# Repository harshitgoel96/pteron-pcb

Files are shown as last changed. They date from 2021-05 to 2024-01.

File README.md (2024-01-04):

# Pteron36 Split Keyboard
## Intro 
Pteron36 PCB Render   

This project is the split evolution of the [pteron-pcb](https://github.com/Kraken-Jokes/pteron-pcb) project, which itself is the evolution of the [Pteron-Keyboard](https://github.com/FSund/pteron-keyboard) project, an incredible ergonomic keyboard that was handwired only.

The keyboard is being desinged to be used with [Miryoku-layout](https://github.com/manna-harbour/miryoku), this layout out aims to have efficient use of split keyboard.

NOTE: The keyboard design has reached its goal, I will not be doing any more development on this board. The support will still be provided. Any issues found by community will be addressed.
NOTE: Update Jan 4th, 2023, a few people have reached out to me with intentions to use the 38key version of the keyboard. The firmware changes have not been merged with QMK mainline yet. For the timebeing, please use this [forked branch to use 38key firmware](https://github.com/harshitgoel96/qmk_firmware/tree/pteron36_38/keyboards/pteron36). I will be working to update the firmware and merge it into the mainline.

#### BOM
| Component | part number | QTY | Comment |
| --- | --- | --- | --- |
| PCB | Gerber in release section | 2 | |
| Diode | 1n4148, SOD123 for smd, or Through hole | 38/36/34  | |
| ProMicro/Bluemicro  | | 2 | Firmwaree not merged with QMK/ZMK, reach out to me on how to build the firmware  |
| TRRS Jack | PJ-320A | 2 | |
| Switches | Cherry, Alps, Choc | 38/36/34  | check PCB compatibility section for more infromation |
| Keycaps | your choice | 38/36/34  | |
| TRRS Cable | TRRS cables have 3 black rings, make sure to check the number | 1 | |

#### BOM for optional components
| Component | part number | QTY | Comment |
| --- | --- | --- | --- |
| Mini tactile switch | PTS526 SMG15 SMTR2 LFS | 2 | You can use tweasers to Reset promicro |
| Rotary Encoder | EC11 | 2 | QMK, VIAL ✔️ ZMK 🚧 |
| OLED | 128x32 SSD1306 I2C | 2 | QMK, VIAL ✔️ ZMK 🚧 |

## Built keyboard
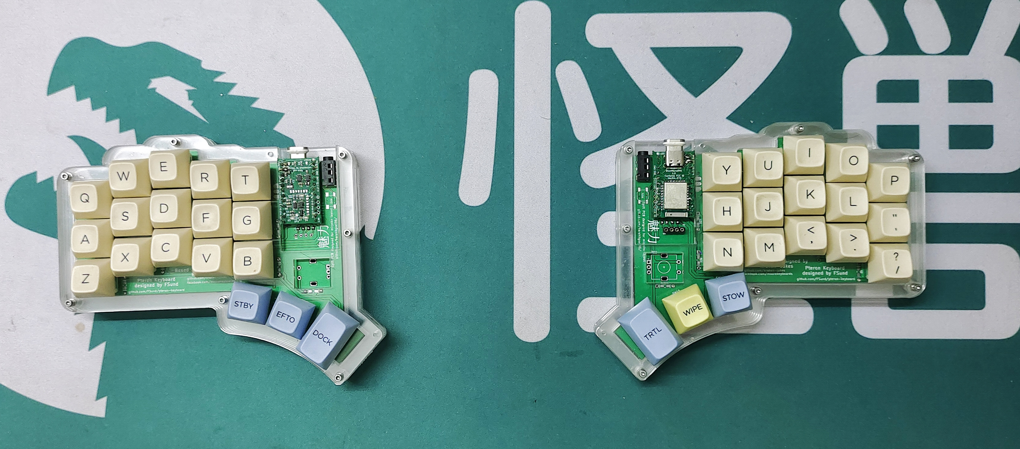
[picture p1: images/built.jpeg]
Pteron36 keyboard


## Build guide
Build guide is added in BUILD.md file.

## Firmware file
Pteron36 has been merged into QMK master with support for miryoku and via. VIA config in available in release section.
Pteron36 has been merged into VIAL QMK fork. 

## Important
The PCB and the case have been tested with MX Switches. 

### PCB compatibility matrix
| PCB version | MX Support | Alps Support | Choc support | Remark |
|---|---|---|---|---|
| V1.1.0 | :heavy_check_mark: |:heavy_check_mark: | :x: | |
| V1.2.0 | :heavy_check_mark: |:heavy_check_mark: | :heavy_check_mark: | |
| V1.3.0 | :heavy_check_mark: |:heavy_check_mark: | :heavy_check_mark: | Cleaner trace routing, added mounting holes |
| V1.4.0 | :heavy_check_mark: |:heavy_check_mark: | :heavy_check_mark: | Replaced sharp angle with curves, more cleaner pcb look |
To use choc switches, make sure to use V1.2.0 files from release section.

### Case compatibility

| Case Type | MX Support | Alps Support | Choc support |
|---|---|---|---|
| Acrylic | :heavy_check_mark: |:x: | :exclamation: Untested, plate need to be lasered on 2mm sheet |
| 3D Printed | 	:construction: Design complete, testing first prototypes |:x: | 	:construction: Design complete, testing first prototypes |

Tenting support added, need M4 screws for tenting holes.
### Acrylic Case assembly
Keyboard supports both ProMicro, and nrf52840 based Bluetooth promicro (bluemicro,nice!nano, etc). The case height will be different to accomodate batteries.
The case designed to be done 3mm acrylic.
Screw M2 6mm 36 nos
Standoff HEX M2 6mm or 9mm 18 nos

For tenting you need.
4x M4 25mm-30mm screws.
4x M4 15mm screws.
8x M4 dome nuts for screw bottom.
8x M4 nut for holding case at required height.
#### Case config for ProMicro
All 4 files need to be cut twice so total 8 pieces. 4 per half.
Screw and standoff needs to be M2. Standoff lenght will be 6mm. Screw length will be 5-6mm. 

#### Case config for Bluemicro, Nine!nano
The case will be taller by 3mm to accomodate battery. This is assuming battery battery thickness is between 3mm - 4mm. For thickerbattery add close layer and standoff length as required.
Close.dfx will be cut 4 times, rest all 3 files need to be cut twice so total 10 pieces. 5 per half.
Screw and standoff needs to be M2. Standoff lenght will be 9mm. Screw length will be 5-6mm.

## ToDo List (In order or priority)
* Add build guide. :construction:
* OLED Support in ZMK  :construction:. OLED working in QMK now  :heavy_check_mark: 
* Encoder Support in ZMK  :construction:. Encoder working in QMK now  :heavy_check_mark: 
* Get firmware merged and ZMK.

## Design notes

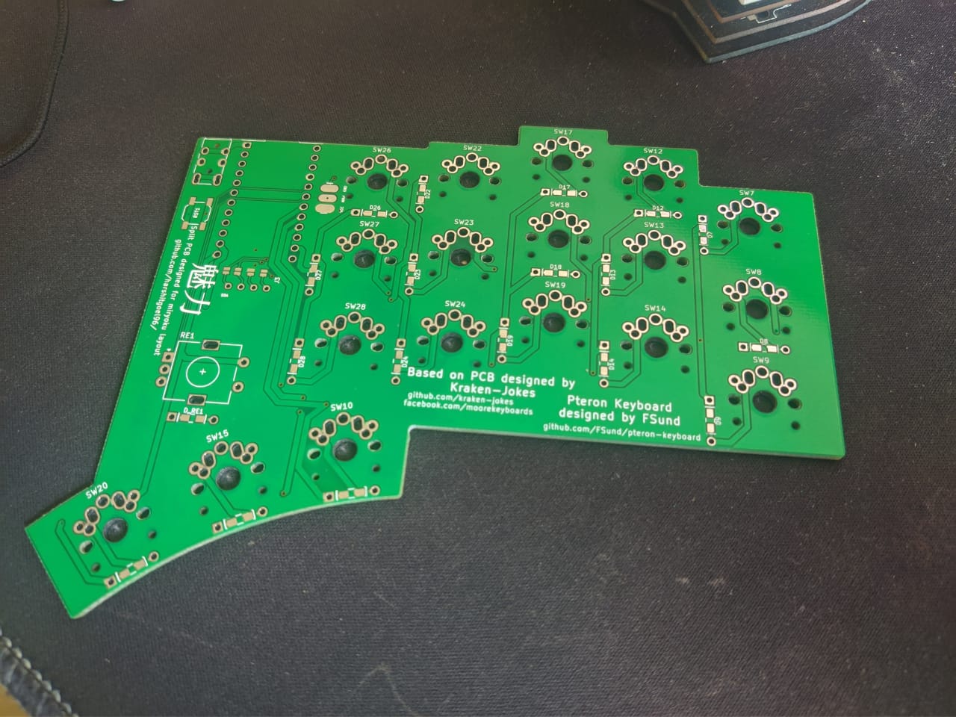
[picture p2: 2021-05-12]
images/proto-pcb.jpeg

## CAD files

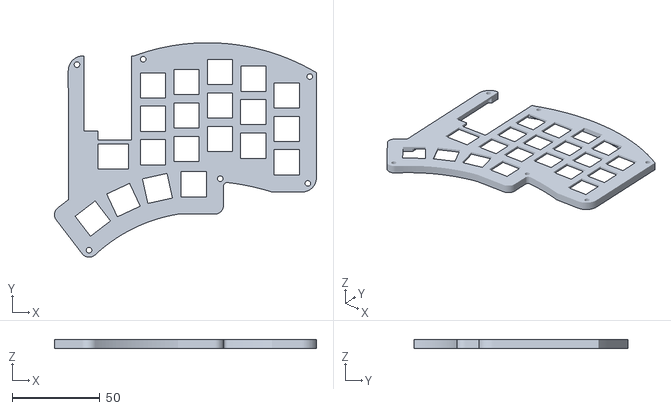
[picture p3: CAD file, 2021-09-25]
Case files/3d-case/38/top.stl
149.3 x 122.2 x 5.00

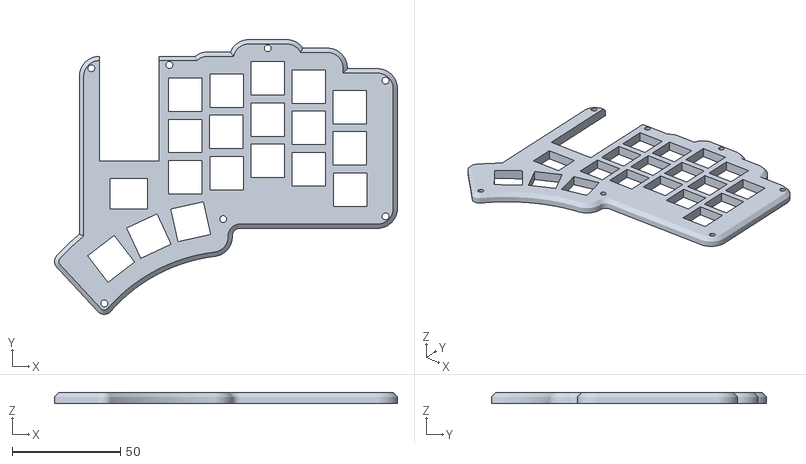
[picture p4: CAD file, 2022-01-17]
Case files/3d-case/cherry-top-new.stl
158.8 x 127.2 x 5.10

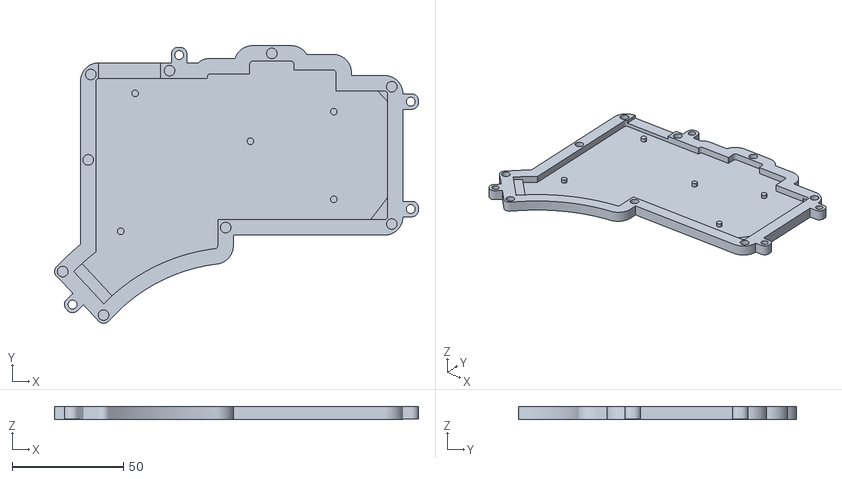
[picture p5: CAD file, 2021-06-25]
Case files/3d-choc/plate-cherry.stl
163.9 x 125.1 x 5.71

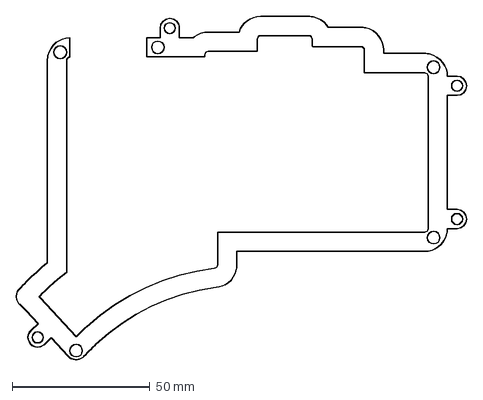
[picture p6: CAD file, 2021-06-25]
Case files/acrylic-tenting/open.dxf
163.5 x 124.6 mm

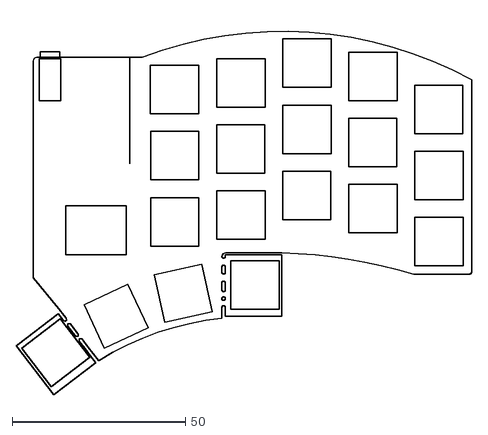
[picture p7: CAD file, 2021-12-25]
mx-pcb/base-plate/Pteron36v0-brd.dxf
131.3 x 109.3

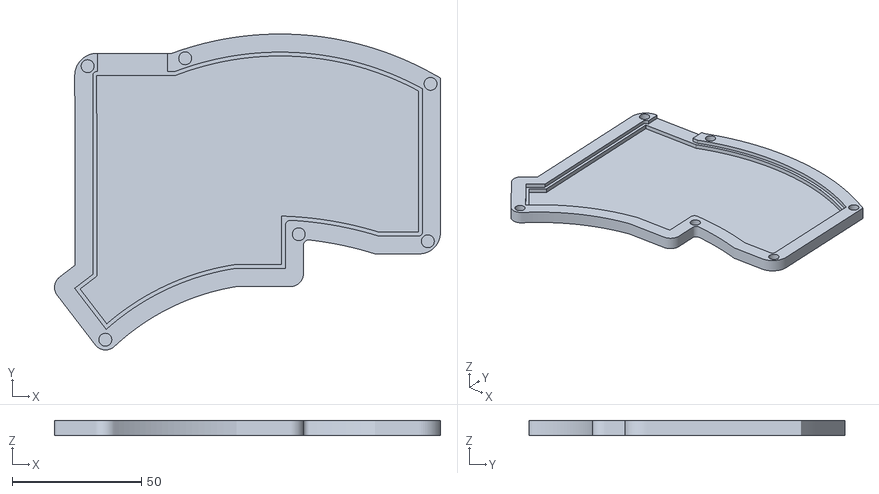
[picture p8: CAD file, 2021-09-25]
Case files/3d-case/38/Bottom.stl
149.3 x 122.2 x 5.75

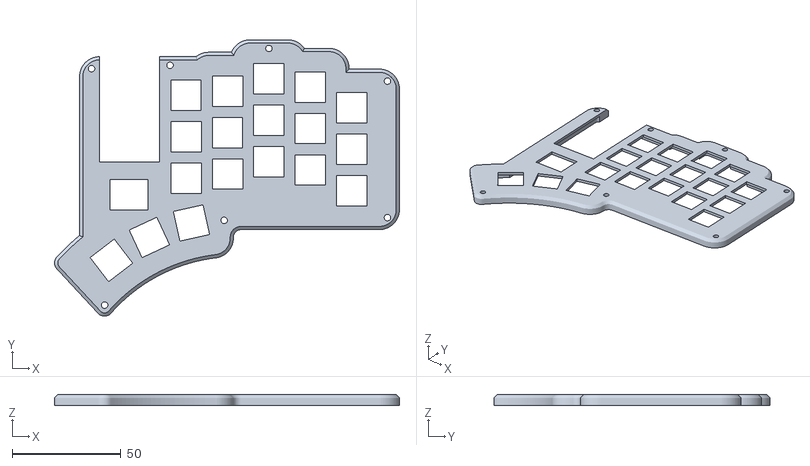
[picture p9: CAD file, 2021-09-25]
Case files/3d-case/cherry-top.stl
158.8 x 127.2 x 5.00

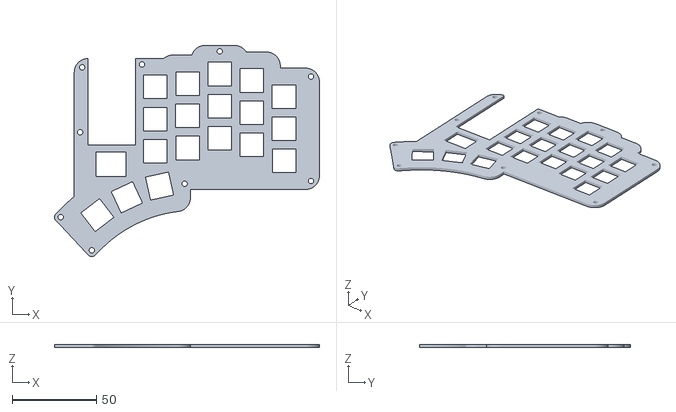
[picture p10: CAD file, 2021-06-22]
Case files/3d-choc/plate-choc.stl
156.9 x 125.1 x 2.00

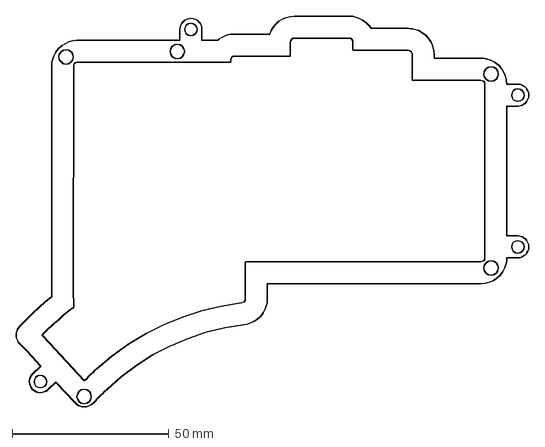
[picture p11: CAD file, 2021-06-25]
Case files/acrylic-tenting/close.dxf
163.5 x 124.6 mm

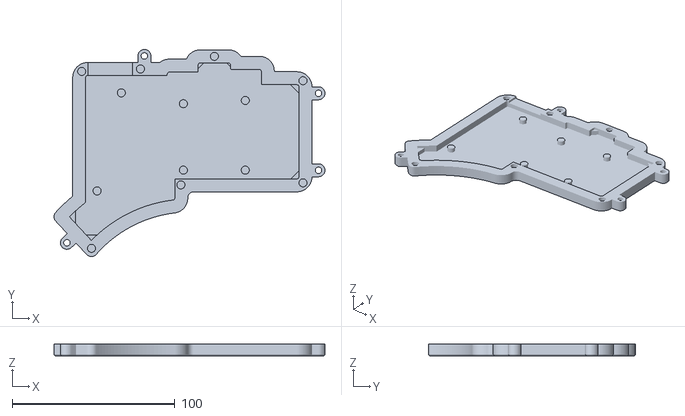
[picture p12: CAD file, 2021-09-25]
Case files/3d-case/base.stl
166.8 x 127.4 x 7.60

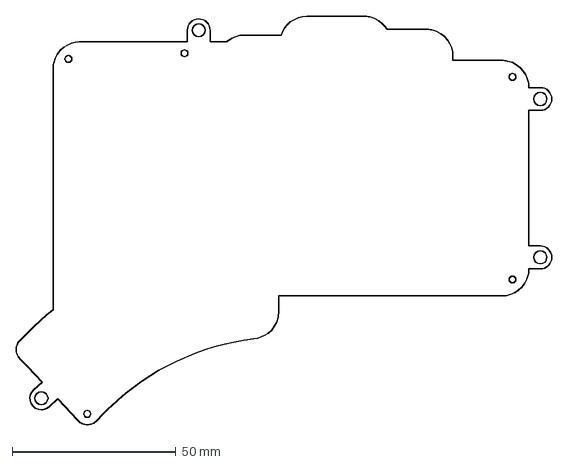
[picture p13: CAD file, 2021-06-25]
Case files/acrylic-tenting/bottom.dxf
163.5 x 124.6 mm

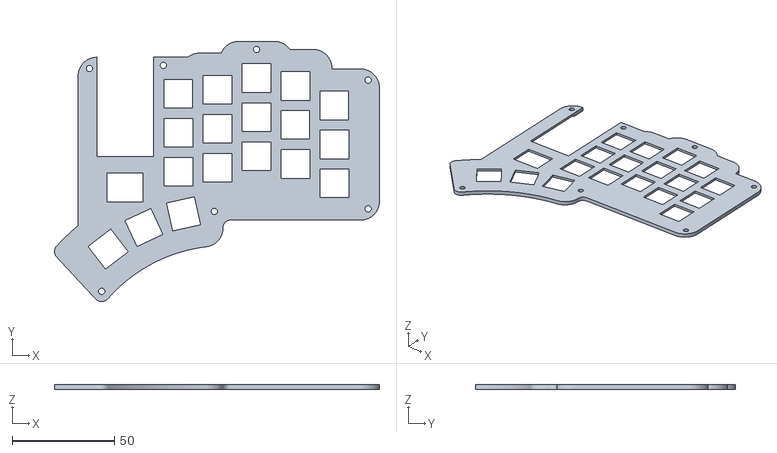
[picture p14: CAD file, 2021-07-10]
Case files/3d-case/choc-top.stl
158.8 x 127.2 x 2.20

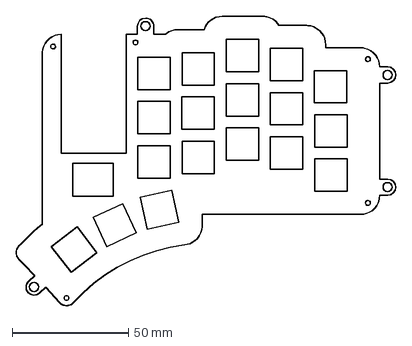
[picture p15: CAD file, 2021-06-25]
Case files/acrylic-tenting/plate.dxf
163.5 x 124.6 mm

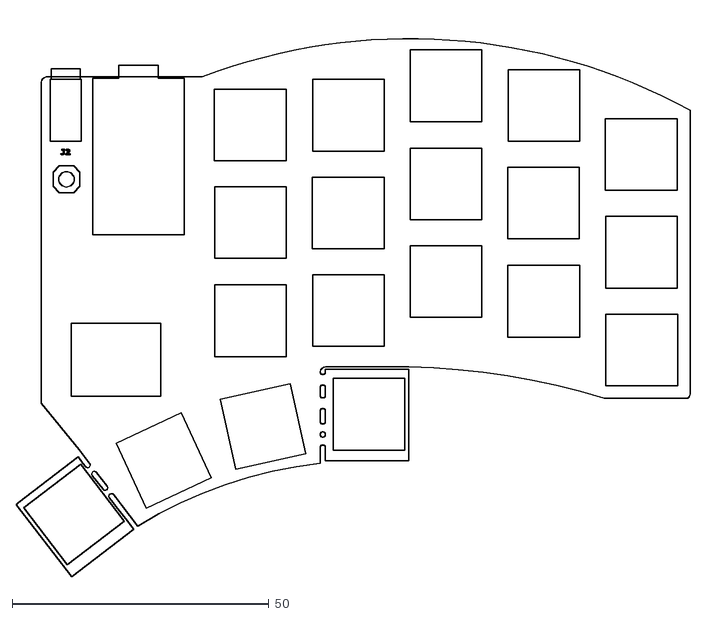
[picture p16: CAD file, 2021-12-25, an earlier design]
Case files/base-plate/Pteron36v0-brd.dxf
131.3 x 109.3

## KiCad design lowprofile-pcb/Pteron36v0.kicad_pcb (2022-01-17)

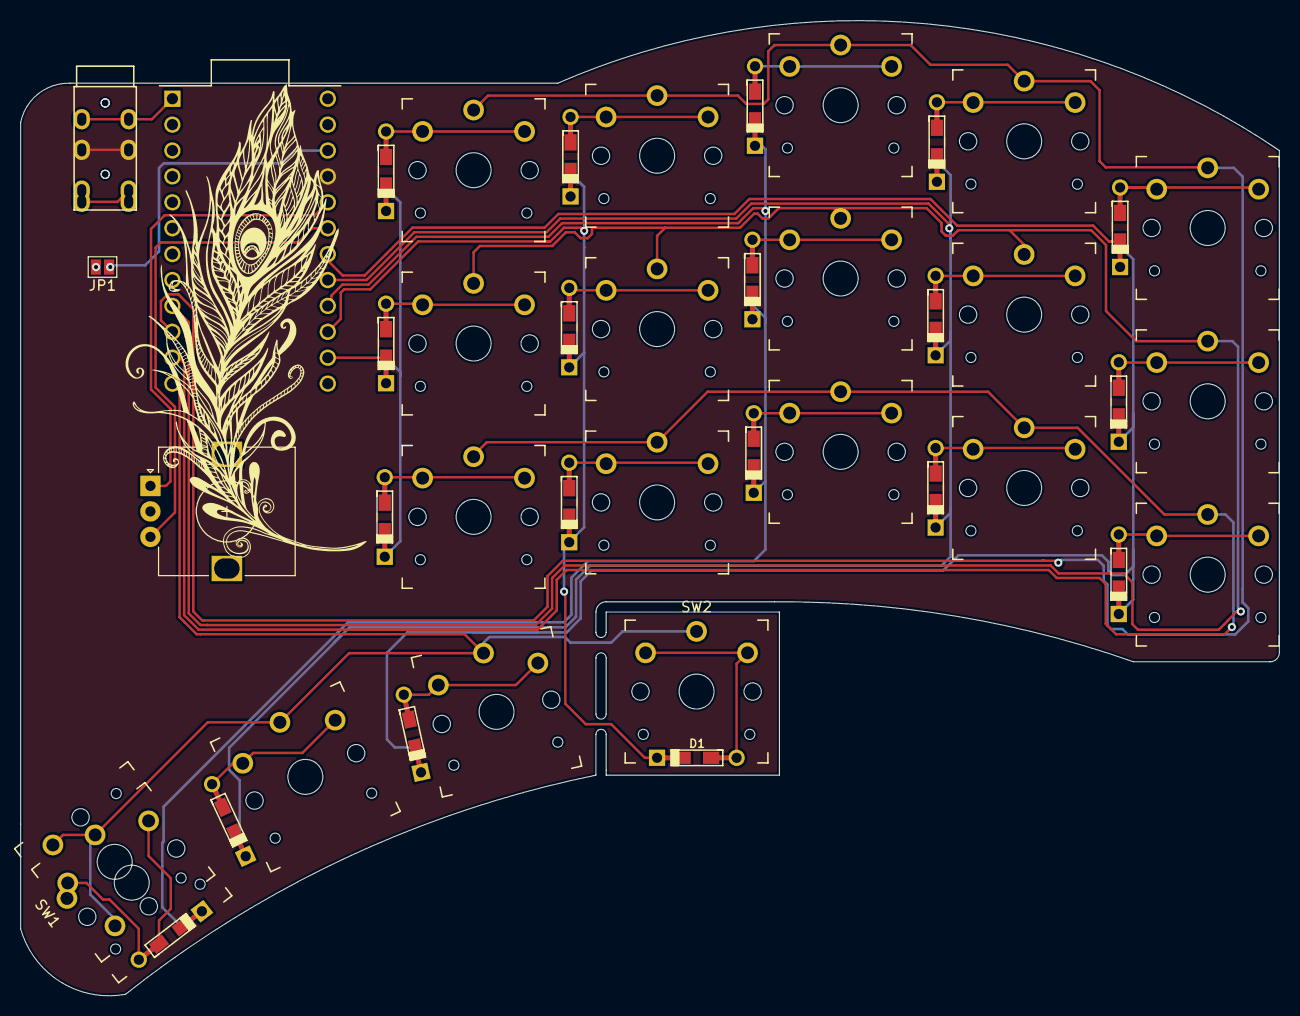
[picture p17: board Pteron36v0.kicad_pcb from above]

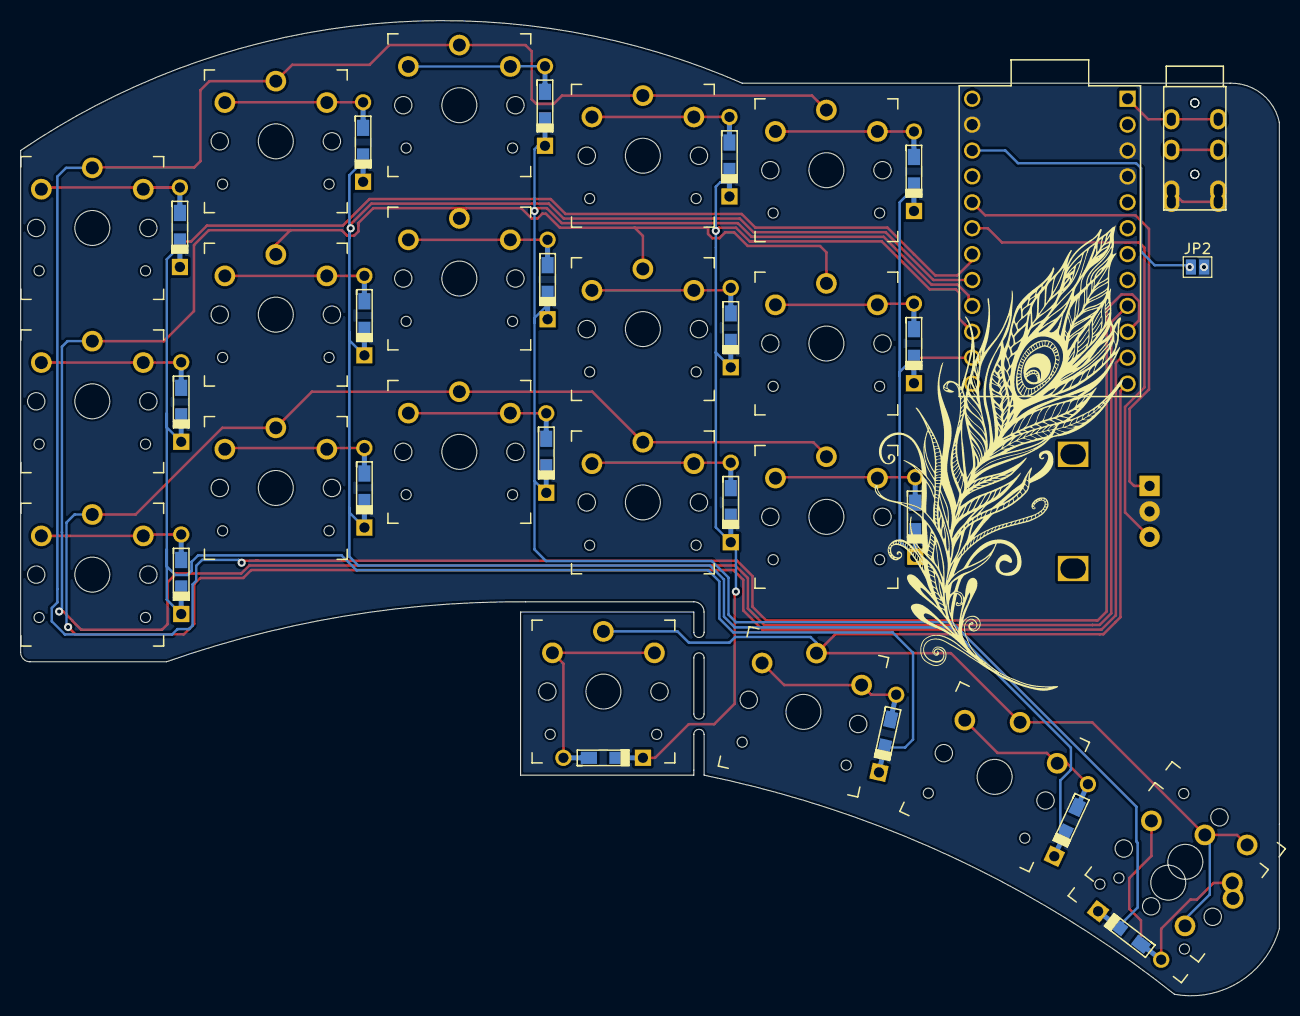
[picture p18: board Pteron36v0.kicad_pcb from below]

Board: 2 copper layers, 123.5 x 95.6 mm, 47 parts (3 on the bottom side), 34 nets.

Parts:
D1, D7, D8, D9, D10, D12, D13, D14, D15, D17, D18, D19, D20, D22, D23, D24, D26, D27, D28: 1N4148; Diode-dual
EN_1: Rotary_Encoder; RotaryEncoder_Alps_EC12E_Vertical_H20mm
J1, J2: AudioJack4; TRRS-PJ-320A
JP1, JP2: JUMPER-PAD-2-NO; SolderJumper-2_P1.3mm_Open_Pad1.0x1.5mm
LOGO3, LOGO4: LOGO-OTL; peacock-medium
SW1, SW2, SW7, SW8, SW9, SW10, SW12, SW13, SW14, SW15, SW17, SW18, SW19, SW20, SW22, SW23, SW24, SW26, SW27, SW28: SW_PUSH; PG1350_reversible
U1: ProMicro

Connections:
/Col1: D7.1 (K), D8.1 (K), D9.1 (K), D10.1 (K), U1.18 (F6)
/Col2: D12.1 (K), D13.1 (K), D14.1 (K), D15.1 (K), U1.17 (F7)
/Col3: D17.1 (K), D18.1 (K), D19.1 (K), D20.1 (K), U1.16 (B1)
/Col4: D1.1 (K), D22.1 (K), D23.1 (K), D24.1 (K), U1.15 (B3)
/Col5: D26.1 (K), D27.1 (K), D28.1 (K), U1.14 (B2)
/RotA: EN_1.A, U1.20 (F4)
/RotB: EN_1.B, U1.19 (F5)
/Row1: SW7.1, SW12.1, SW17.1, SW22.1, SW26.1, U1.10 (E6)
/Row2: SW8.1, SW13.1, SW18.1, SW23.1, SW27.1, U1.9 (D7)
/Row3: SW9.1, SW14.1, SW19.1, SW24.1, SW28.1, U1.11 (B4)
/Row4: SW1.1, SW2.1, SW10.1, SW15.1, SW20.1, U1.12 (B5)
/Serial: J1.4, J2.4, U1.1 (TX)
GND: EN_1.C, J1.1, J1.2, J2.1, J2.2, JP1.2, JP2.2, U1.3 (GND), U1.4 (GND), U1.23 (GND)
unnamed: D1.2 (A), SW2.2
unnamed: D7.2 (A), SW7.2
unnamed: D8.2 (A), SW8.2
unnamed: D9.2 (A), SW9.2
unnamed: D10.2 (A), SW10.2
unnamed: D12.2 (A), SW12.2
unnamed: D13.2 (A), SW13.2
unnamed: D14.2 (A), SW14.2
unnamed: D15.2 (A), SW15.2
unnamed: D17.2 (A), SW17.2
unnamed: D18.2 (A), SW18.2
unnamed: D19.2 (A), SW19.2
unnamed: D20.2 (A), SW1.2, SW20.2
unnamed: D22.2 (A), SW22.2
unnamed: D23.2 (A), SW23.2
unnamed: D24.2 (A), SW24.2
unnamed: D26.2 (A), SW26.2
unnamed: D27.2 (A), SW27.2
unnamed: D28.2 (A), SW28.2
unnamed: JP1.1, JP2.1, U1.22 (RST)
VCC: J1.3, J2.3, U1.21 (VCC)

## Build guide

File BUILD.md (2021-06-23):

## Build Instruction

This is not a complete guide, its WIP. I am giving important pointers for it right now.

* Diode direction, diodes are polarised, and will connect only one way for proper fuctioning. Both SMD and THT have line on them to signify the Cathod side of the diode. The leg/side with line will go towards the Square hole side of diode pads. This is illustrated in the photo below.
Diode line should face the Square hole
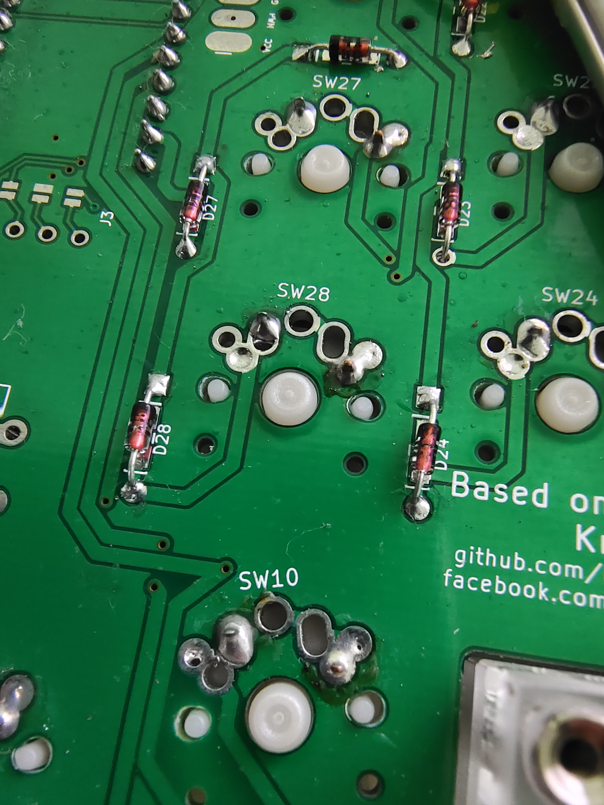
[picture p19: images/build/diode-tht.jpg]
Diode line should face the Square hole


* ProMicro Allightment in done based on TX0 pin, the TX0 pin should go into the square hole on the promicro holes.
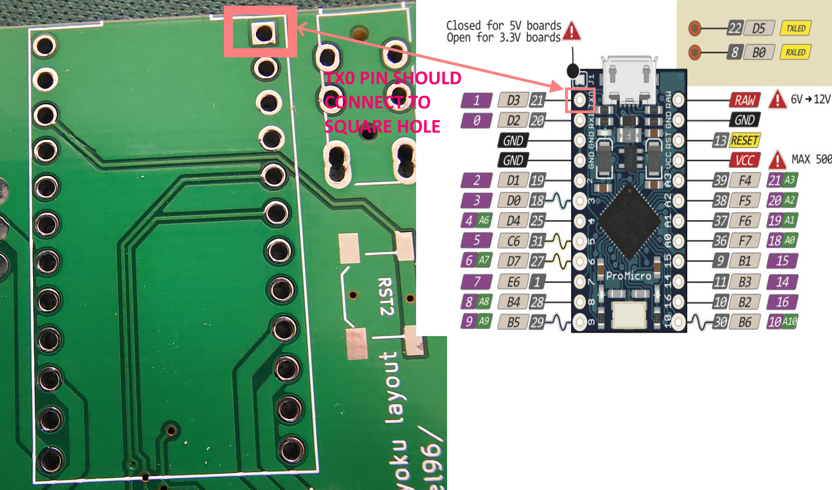
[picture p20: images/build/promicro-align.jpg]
The promicr TX pin should be aligned with Square hole on pcb.


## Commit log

2021-04-12 add split wiring for standard Pteron56v0
    [Pteron56v0.kicad_pcb, Pteron56v0.sch]
2021-04-12 split36 version
    [Pteron56v0.kicad_pcb, Pteron56v0.sch]
2021-04-12 finalised the design, add mounting holes
    [Pteron56v0.kicad_pcb, Pteron56v0.sch]
2021-04-12 small improvements
    [Pteron56v0.kicad_pcb]
2021-04-12 added gerber files
    [Pteron56v0-B_Cu.gbr, Pteron56v0-B_Mask.gbr, Pteron56v0-B_Paste.gbr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]
2021-04-13 remove top row.
    [Pteron56v0.kicad_pcb, Pteron56v0.sch]
2021-04-13 simplified wiring, lily58 like pro micro placement
    [Pteron56v0.kicad_pcb, Pteron56v0.sch]
2021-04-13 made small changes for mounting holes
    [Pteron56v0.kicad_pcb, Pteron56v0.sch]
2021-04-13 added top and bottom gerber
    [Pteron56v0-Edge_Cuts.dxf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]
2021-04-13 finished rev1 for pteron36
    [Base Plate.dxf, Pteron56v0-brd.dxf, Pteron56v0.kicad_pcb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]
2021-04-13 added images, added project info
    [Pteron56v0-B_Cu.gbr, Pteron56v0-B_Mask.gbr, Pteron56v0-B_Paste.gbr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]
2021-04-14 added oled support
    [Pteron56v0-B_Cu.gbr, Pteron56v0-B_Mask.gbr, Pteron56v0-B_Paste.gbr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]
2021-04-14 added oled, clean silkscreen
    [Pteron56v0-B_Cu.gbr, Pteron56v0-B_Mask.gbr, Pteron56v0-B_Paste.gbr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]
2021-04-15 add oled, pwm pad, reset switch, moved trrs closer to top, to get simpler casefiles
    [Pteron56v0-B_Cu.gbr, Pteron56v0-B_Mask.gbr, Pteron56v0-B_Paste.gbr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]
2021-04-16 rename files to pteron36, to reflect correct keysize. add logo and text
    [Pteron36v0.kicad_pcb, Pteron36v0.sch, Pteron56v0-Edge_Cuts.dxf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]
2021-04-17 add encoder, cleanup files, rename files.
    [Pteron36v0-B_Cu.gbr, Pteron36v0-B_Mask.gbr, Pteron36v0-B_SilkS.gbr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]
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2021-04-25 added choc and mx support in single pcb.
    [Pteron36v0-B_Cu.gbr, Pteron36v0-B_Mask.gbr, Pteron36v0-B_SilkS.gbr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]
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2021-05-12 updated pcb
    [Pteron36v0.kicad_pcb]
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2021-05-13 add known issue about choc switch in main branch
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2021-05-23 update hole size for standoff
    [closed.dxf, open.dxf, plate.dxf]
2021-06-18 updated case
    [3d-base.stl, 3d-cherry-top-hf.stl, 3d-choc-top.stl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]
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2021-06-21 add case files
    [3d-base.stl, 3d-cherry-top-hf.stl, 3d-choc-top.stl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]
2021-06-22 add 3d case file for choc switch with tenting
    [3d-choc-bottom.stl, 3d-choc-top.stl]
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2021-06-25 update 3d case files
    [3d-choc-bottom.stl, base.stl, plate-cherry.stl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]
2021-06-25 add acrylic case with tent holes
    [bottom.dxf, close.dxf, open.dxf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]
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2021-06-26 update case file for better diode clearance, some chamfer, and countersunk
2021-06-30 add changes to base. thicken pcb post, better tenting support.
2021-07-06 use crkbd footprint for better manufacturing
    [Pteron36v0-B_Cu.gbr, Pteron36v0-B_Mask.gbr, Pteron36v0-B_SilkS.gbr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]
2021-07-07 update footprint for better support from manuf
    [Pteron36v0.kicad_pcb]
2021-07-07 reroute pcb, just for kicks
    [Pteron36v0-B_Cu.gbr, Pteron36v0-B_Mask.gbr, Pteron36v0-B_SilkS.gbr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]
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2021-07-10 final pcb
    [Pteron36v0-B_Adhes.gbr, Pteron36v0-B_Cu.gbr, Pteron36v0-B_Mask.gbr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]
2021-07-10 generate final gerber
    [Pteron36v0-B_Adhes.gbr, Pteron36v0-B_Cu.gbr, Pteron36v0-B_Mask.gbr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]
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2021-07-10 update case files
    [base.stl, bottom.dxf, cherry-top.stl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]
2021-07-12 clean up pads
    [Pteron36v0-B_Adhes.gbr, Pteron36v0-B_Cu.gbr, Pteron36v0-B_Mask.gbr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]
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2021-07-14 keebio footprint
    [Pteron36v0-B_Adhes.gbr, Pteron36v0-B_Cu.gbr, Pteron36v0-B_Mask.gbr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]
2021-07-22 rename folder for better separation between original and lowprofile pcb
    [Pteron36v0-B_Adhes.gbr, Pteron36v0-B_Cu.gbr, Pteron36v0-B_Mask.gbr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]
2021-07-22 rename folder
    [Pteron36v0-B_Adhes.gbr, Pteron36v0-B_Cu.gbr, Pteron36v0-B_Mask.gbr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]
2021-07-25 add separate pcb for mx alps
    [Pteron36v0-B_Adhes.gbr, Pteron36v0-B_Cu.gbr, Pteron36v0-B_Mask.gbr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]
2021-07-28 cleaner tracing
    [Pteron36v0.kicad_pcb]
2021-07-28 updated board outline and wiring
    [Pteron36v0.kicad_pcb]
2021-07-28 regen gerber LP
    [Pteron36v0-B_Adhesive.gbr, Pteron36v0-B_Cu.gbr, Pteron36v0-B_Mask.gbr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]
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2021-07-28 update outline with curves, cleaup wiring
    [Pteron36v0.kicad_pcb]
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2021-07-28 finalise art and board
    [Pteron36v0-B_Adhes.gbr, Pteron36v0-B_Adhesive.gbr, Pteron36v0-B_Cu.gbr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]
2021-07-28 finalize low profile pcb
    [Pteron36v0-B_Adhesive.gbr, Pteron36v0-B_Cu.gbr, Pteron36v0-B_Mask.gbr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]
2021-07-28 ready for multi slot version of pcb
    [Pteron36v0.kicad_pcb, Pteron36v0.kicad_sch]
2021-07-28 updaate pcb
    [Pteron36v0.kicad_pcb]
2021-07-28 eureka of super finish
    [Pteron36v0.kicad_pcb]
2021-07-28 super is ready
    [Pteron36v0-B_Adhesive.gbr, Pteron36v0-B_Cu.gbr, Pteron36v0-B_Mask.gbr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]
2021-07-28 verify gerber
    [Pteron36v0-B_Adhes.gbr, Pteron36v0-B_Adhesive.gbr, Pteron36v0-B_Cu.gbr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]
2021-08-06 introduce the snapable pcb with 4 config of keyboard possible
    [Pteron36v0-B_Adhes.gbr, Pteron36v0-B_Adhesive.gbr, Pteron36v0-B_Cu.gbr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]
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2021-08-18 almost ready final super pcb
    [Pteron36v0.kicad_sch]
2021-09-25 add stl for 38 key variant case, add 1.5 u on lowprofile keyboard
    [Bottom.stl, Pteron36v0.kicad_pcb, Pteron36v0.kicad_sch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]
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2022-01-17 major changes in pcb, choc support removed from universal pcb, and made mx/alps only, this is because a choc spec lowprofile pcb exists. no more need for universal pcb
    [Pteron36v0-B_Adhesive.gbr, Pteron36v0-B_Cu.gbr, Pteron36v0-B_Mask.gbr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]
2022-01-17 add 4-th key in thumb for removable config
    [Pteron36v0.kicad_pcb, Pteron36v0.kicad_sch]
